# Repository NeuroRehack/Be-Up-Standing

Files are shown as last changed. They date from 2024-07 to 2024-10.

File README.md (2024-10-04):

## [🏠 HOME](./README.md) | [🔧 Firmware](Firmware/README.md) | [💻 Software](Software/README.md) | [📊 Analysis](Analysis/README.md)
# Desk Positioning System 

This project aims to monitor the usage of a standing desk by measuring its height and detecting whether someone is present. The Desk Positioning System utilizes an Omega2 Pro SBC (Single-Board Computer) to read data from a human presence sensor and a distance sensor, storing this data localy. The data is periodically uploaded to Google Drive for easy remote access and analysis.

<p align="center">
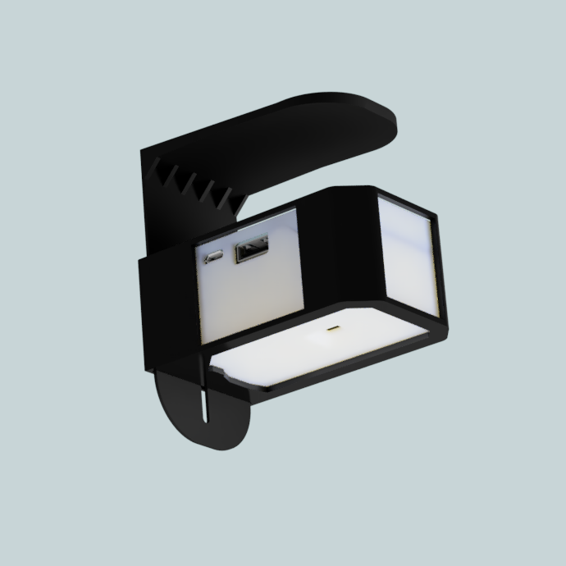
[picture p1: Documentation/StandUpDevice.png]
  
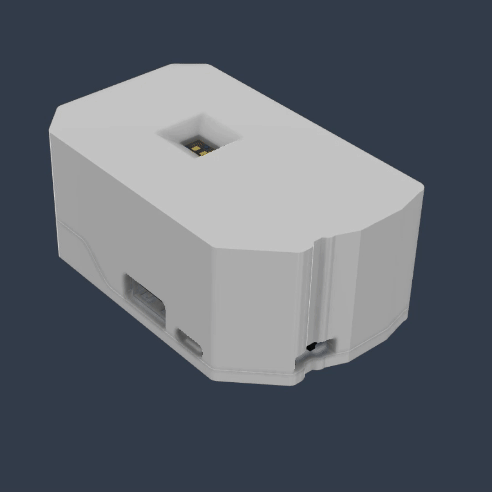
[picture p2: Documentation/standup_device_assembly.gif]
  
</p>

## Features
- **Desk Height Monitoring:** A laser distance sensor measures the distance between the desk and the floor, enabling the system to determine whether the desk is in a sitting or standing position.
- **Human Presence Detection:** An mmWave human presence detector identifies if a person is present and whether they are standing or sitting in front of the desk.
- **Data Logging:** Data from the sensors is processed and recorded by the Omega2 Pro, and timestamped using a real-time clock (RTC) module. The data is saved locally and periodically uploaded to Google Drive.
- **Power Management:** Powered by a rechargeable LiPo battery, the system remains operational during power outages.
- **Wi-Fi Connectivity:** The device uploads data to Google Drive when an internet connection is available. In case of network failure, data is stored locally for later upload.
- **Web Interface:** Each device hosts a unique web interface accessible via a specific URL, allowing users to:
  - Configure device settings (e.g., sampling frequency)
  - Start/stop data recording
  - Visualize recorded data in real-time
  - Manage Wi-Fi settings and monitor battery status
- **LED Indicator:** Provides visual feedback on operational status, such as internet connectivity and recording activity.

<p align="center">
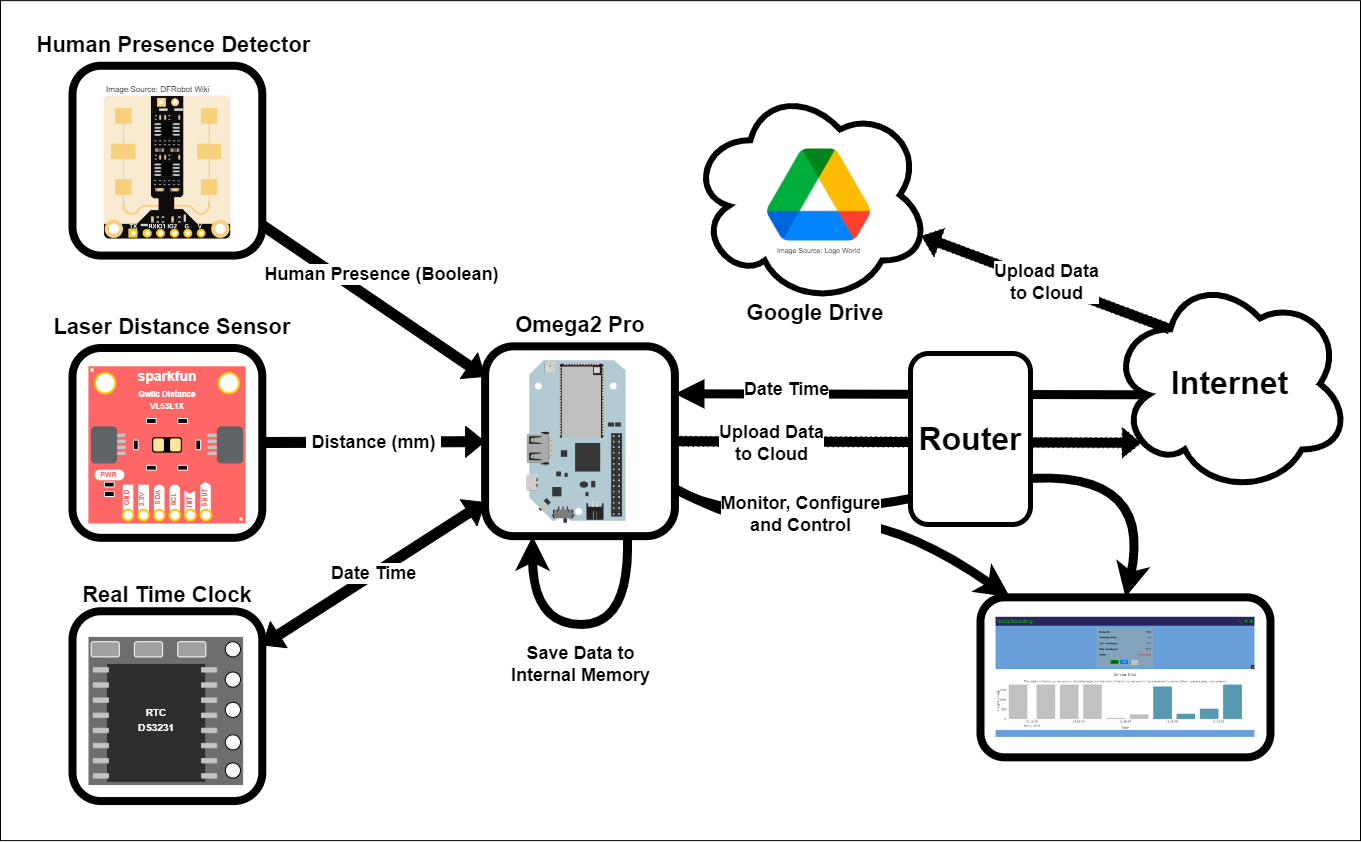
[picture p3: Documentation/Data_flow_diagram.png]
  
</p>

## Repo Overview
- **Firmware:** Contains the code running on the Omega2 Pro, responsible for data collection, processing, and cloud synchronization.
- **Software:** Includes scripts for downloading data from Google Drive
- **Analysis:** Provides instructions for analyzing the collected data to understand desk usage patterns.

## Getting Started
### Assembly and Setup

Follow the instructions in the [Firmware README](Firmware/README.md) to assemble the hardware and install the necessary firmware.

## Software

The scripts in software can be used to navigate, download and delete data from the google drive. For more information see the [Software README](Software/README.md).
## Data Analysis

The data collected by the Desk Positioning System can be analyzed to understand desk usage patterns. Detailed instructions for analyzing the data are available in the [Analysis README](Analysis/README.md).

## Desk Positioning System (DPS)

The Desk Positioning System (DPS) was developed to measure sit-stand desk usage in real-world settings. 
It has been created in collaboration with researchers from the School of Human Movement and Nutrition Sciences 
and the Neuroengineering, Rehabilitation, and Medical Robotics Group at the University of Queensland.

The system monitors desk height, detects human presence, and logs data for analysis. The device is managed through 
a web interface and can upload data to Google Drive.

---

## Getting Started

### Switching the Device On

The DPS device features two ports and one switch:

<p align="center">
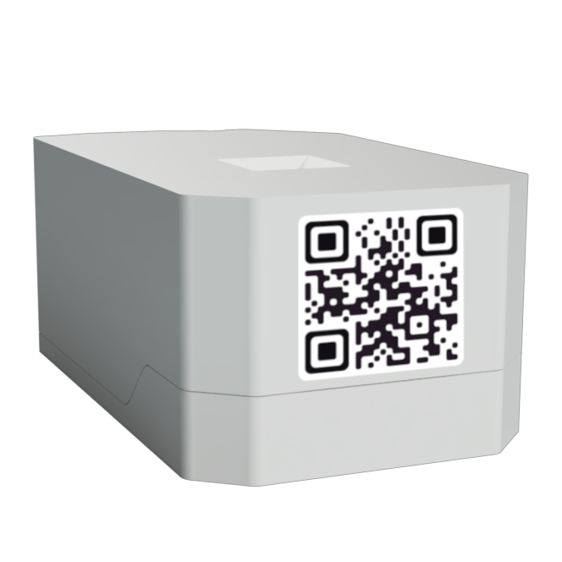
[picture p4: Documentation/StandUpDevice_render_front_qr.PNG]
  
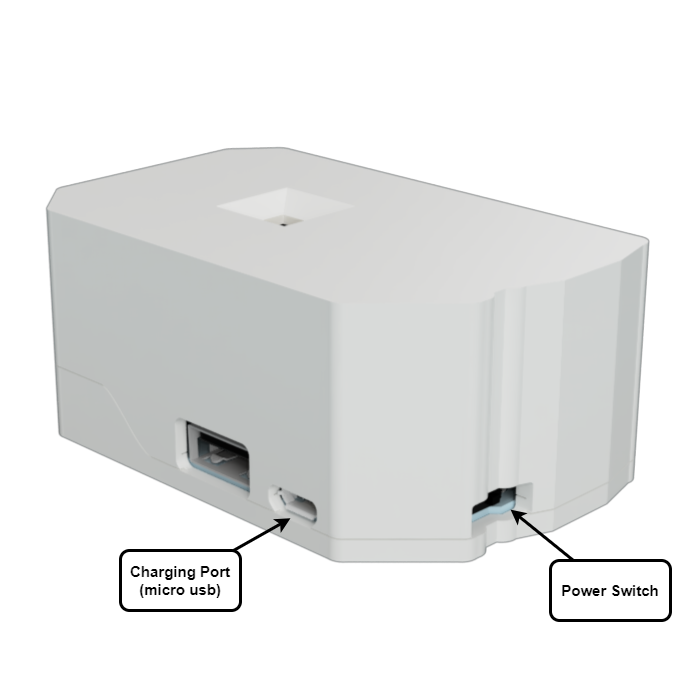
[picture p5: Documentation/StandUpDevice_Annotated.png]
  
</p>

- **USB Port**: Not currently in use.
- **Micro-USB Port**: Used for charging or providing power to the device.
- **Power Switch**: Used to turn the device on and off.

To start the device, switch it on using the power switch (connect it to a power source if necessary). 
The device should automatically start recording data.

### Accessing the Dashboard

To access the device’s dashboard, scan the provided QR code or enter the URL `dps-xxxx.local:5000` in your browser, replacing `xxxx` with the device's unique identifier. Ensure that the device and your computer are on the same network.

The home page asks the user to choose between two profiles, the guest or admin profile (default password : dps12345678). Both profiles allow the user to see the real time data and some of the devices’ parameters, and set the status LED intensity.

<p align="center">
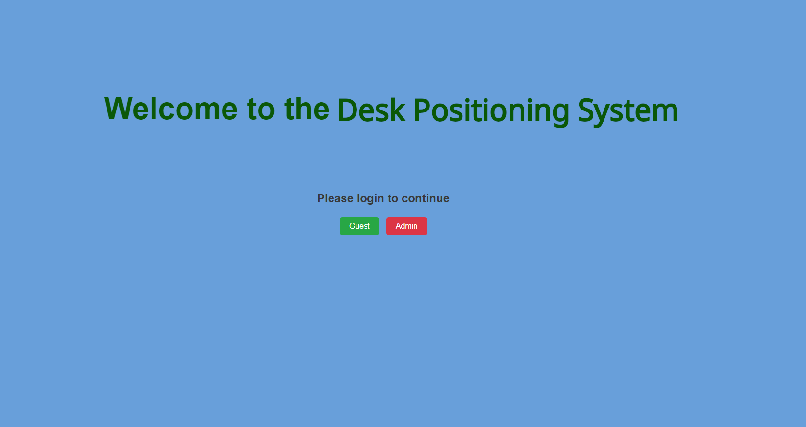
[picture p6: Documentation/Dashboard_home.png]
  
</p>

## Device Operation

Once logged in to the Admin Dashboard, you can monitor the device's parameters, start/stop recordings, and adjust settings.
<p align="center">
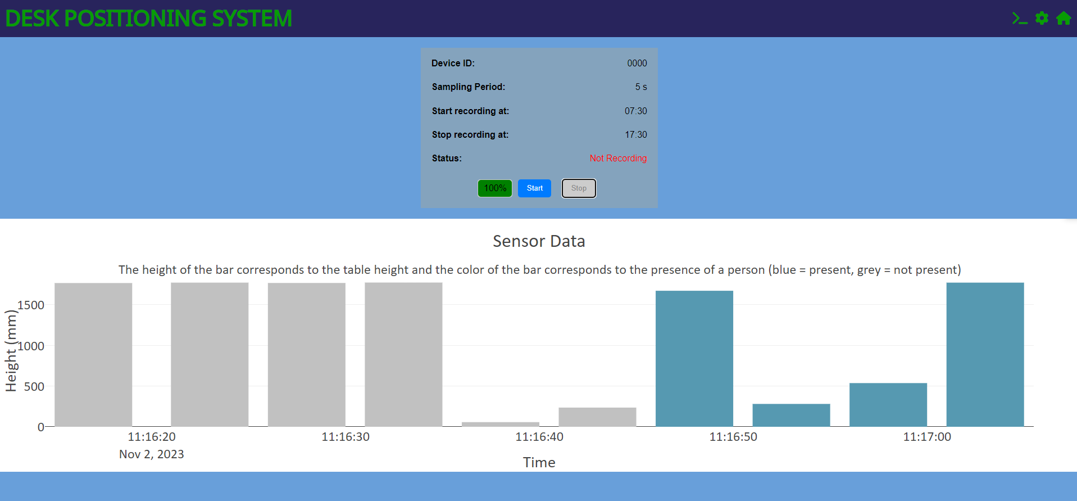
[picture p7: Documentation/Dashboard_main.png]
  
</p>

### Configuration

The settings window allows you to customize the following parameters:

- **ID**: Define a name for a recording session (e.g., `test_001`).
- **Start/Stop Recording**: Specify the time window for active recording.
- **Status LED Intensity**: Adjust the brightness of the status LED.

Advanced settings include:

- **Sampling Period**: Period between data sampling (seconds).
- **Write Period**: Period between writing data to a file.
- **New File Period**: Period after which a new file is created.
- **Upload Period**: Period between attempts of uploading completed files.

<p align="center">
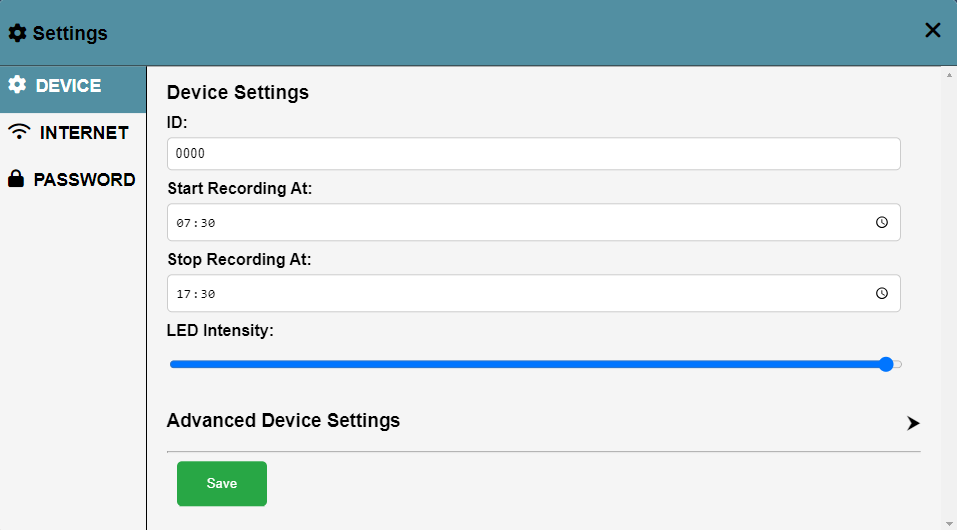
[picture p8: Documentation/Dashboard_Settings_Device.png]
  
</p>

### Recording

Recording starts automatically when the device is switched on, unless it was previously turned off in a non-recording state.

- **Stop Recording**: Press the “Stop Recording” button. The main LED will pulse red.
- **Start Recording**: Press the “Start Recording” button. The LED will pulse green (and blue if connected to internet). If the current time is outside the recording
window set in the configuration file, the colour of the LED will change to purple and pulsate more
slowly.

<p align="center">
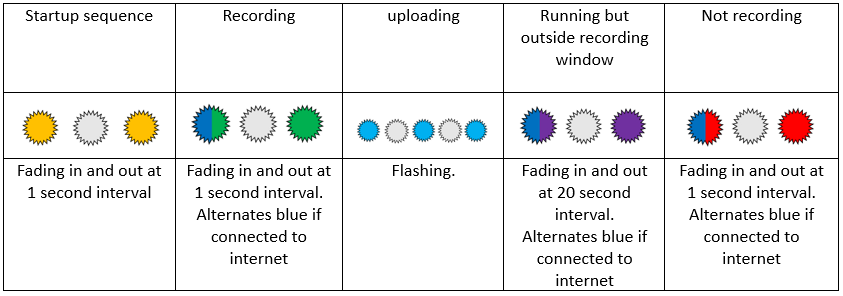
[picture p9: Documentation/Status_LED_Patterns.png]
  
</p>

### Device Placement

Proper placement of the Desk Positioning System (DPS) is crucial for accurate detection and measurement. Below are guidelines for placing the device in different environments:

#### Accurate Detection
- **Single Person Office:** The DPS will correctly detect the presence of the correct person when placed facing the user directly. This setup ensures that the sensor accurately detects both sitting and standing positions.

#### Situations with Inaccurate Measurement
- **Distance Measurement Issues:** When the device is placed at an angle where it cannot properly detect the distance between the table and the surface below, the DPS might still differentiate between sitting and standing, but the measurements will be less accurate.
- **Shared Office:** In a shared office environment, the DPS may not always detect the presence of the correct person if other individuals are within the detection range. It's important to position the device carefully to minimize interference.
- **Open Space Office:** Similar to a shared office, the DPS may not always detect the correct person in an open space office. Ensure the device's front is facing the intended user and minimize the chance of capturing passersby.

#### Incorrect Detection
- **Improper Placement:** If the DPS is placed facing away from the user or in a position where the sensor cannot accurately measure the distance to the surface, it will fail to correctly detect the user’s presence or their sitting/standing state.

#### Placement Tips
- **Orientation:** The device should be placed and oriented such that the front is facing the user, minimizing the chances of capturing passersby.
- **Placement**: Ensure the device is positioned at an angle where the distance sensor can accurately measure the height of the desk. Avoid placing the device in a corner or behind objects that may obstruct the sensors.

<p align="center">
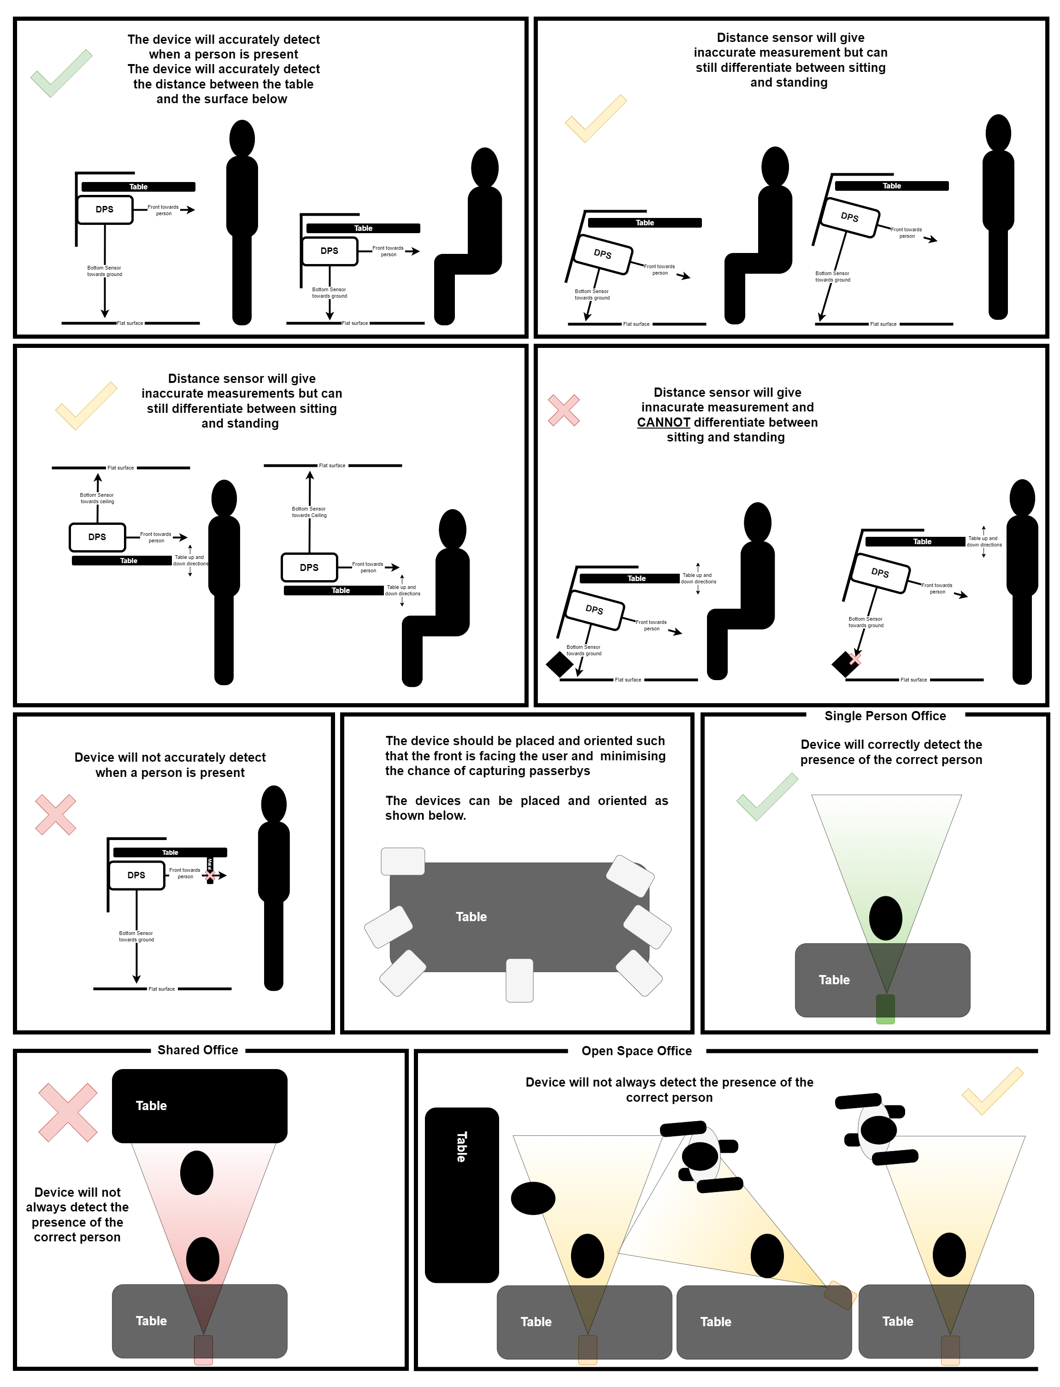
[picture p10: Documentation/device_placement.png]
  
</p>

## Data Handling

### Downloading the Data

Use the `drive_cloner_ui.exe` program to download data from Google Drive (see [Software README](Software/README.md) for more information). The program will sync and download the data, 
then clear the drive. It is recommended to run this program on a single computer to avoid data loss.

### Downloading Data Directly from the Device

If the data has not been uploaded to Google Drive, you can download it directly from the device using [WinSCP](https://winscp.net/eng/index.php). 
Connect your computer to the device’s Wi-Fi or the same network, then use the following credentials:

- **Hostname**: `standup-xxxx.local`
- **Username**: `root`
- **Password**: `beupstanding` (default)

<p align="center">
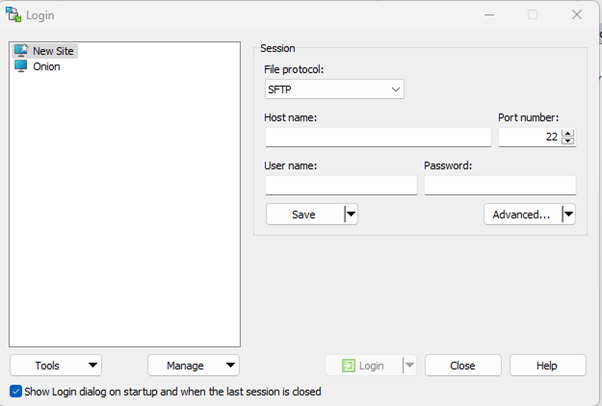
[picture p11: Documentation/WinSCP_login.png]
  
</p>

Once the session is established the folder structure of the device is shown on the right-hand side,
and the folder structure of your computer is shown on the left-hand side. On the device navigate to
the Firmware folder and on the computer navigate to where you would like to download the data to.
On the computer create a folder which name is the ID of the device. You can then simply select the
“data” folder on the device side and drag it to the created folder on the computer side to copy it.

<p align="center">
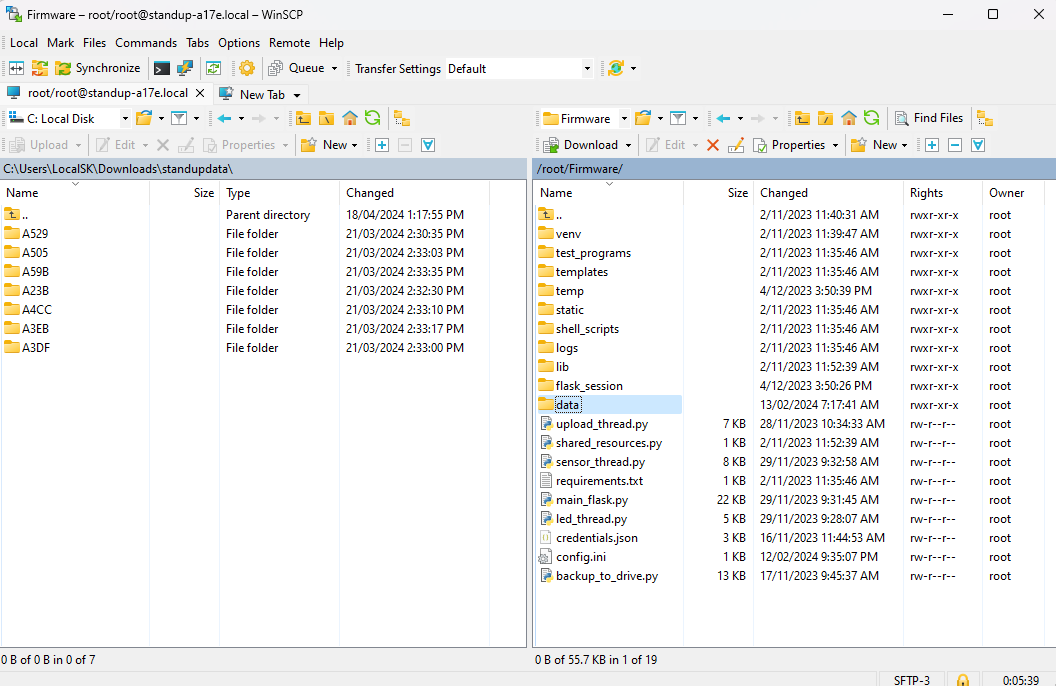
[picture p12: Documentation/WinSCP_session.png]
  
</p>

---
## License

This project is licensed under the GNU General Public License. You may redistribute and/or modify it under the terms of the [GPL version 3](https://www.gnu.org/licenses/gpl-3.0.html) (or any later version) as published by the Free Software Foundation.

For more details, see the [LICENSE](LICENSE) file.

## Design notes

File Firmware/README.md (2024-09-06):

<!-- add a link to go back to main readme file -->
## [🏠 HOME](../README.md) | [🔧 Firmware](./README.md) | [💻 Software](../Software/README.md) | [📊 Analysis](../Analysis/README.md)

## Required material
- [Omega2 Pro](https://onion.io/store/omega2-pro/)
- [DFRobot_mmWave module](https://www.dfrobot.com/product-2282.html)
- [PiicoDev_VL53L1X module](https://www.sparkfun.com/products/14722)
- [SDL_DS3231 module](https://www.jaycar.com.au/rtc-clock-module-for-raspberry-pi/p/XC9044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)
- [LiPo battery 3.7V 1100mAh](https://core-electronics.com.au/polymer-lithium-ion-battery-1000mah-38458.html)
- 5 x Male to Female Jumper wires
- 2 x Male to QWIIC Jumper wires (4-pin)
- USB A to micro USB cable
- M3 Nylon 16mm screws and nuts

## Required equipment
- 3D printer
- Soldering iron
- Hot glue gun (optional)
- Computer
- Internet connection

## Required skills and experience
- 3d printing
- Soldering
- SSH and serial terminal
- Basic knowledge of linux navigation and commands

## Hardware setup 
### Wiring (~15 min)
Once you have all the necessary components, you can start assembling the hardware. The wiring schematic below shows how to connect the various components to the Omega2 Pro. 
This step may require you to solder pins onto some of the sensors. Wiring should take around 10-15 minutes.

<p align="center">
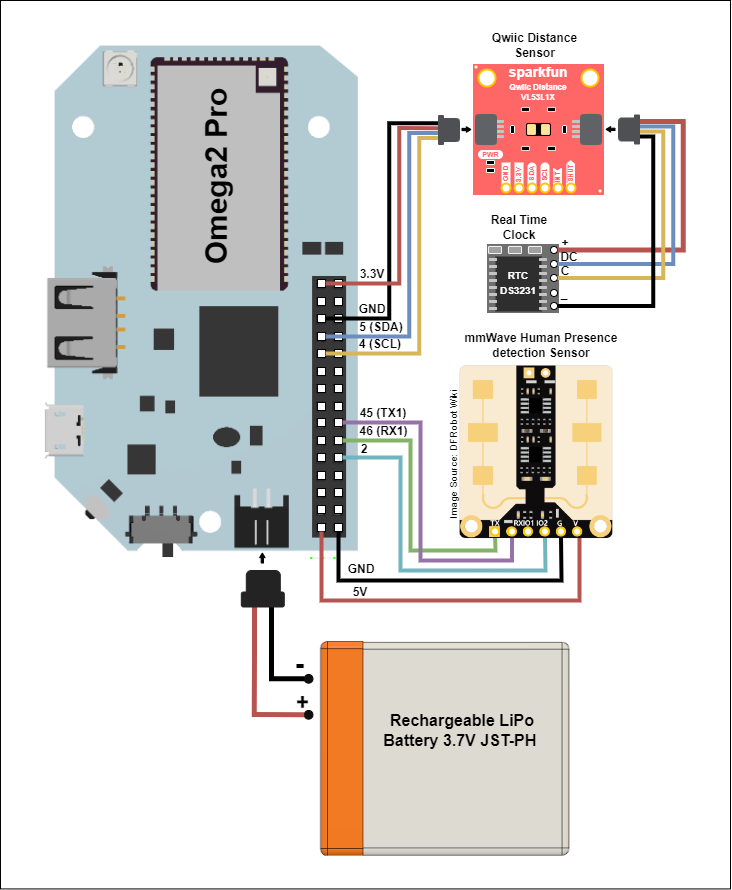
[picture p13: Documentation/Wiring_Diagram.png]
  
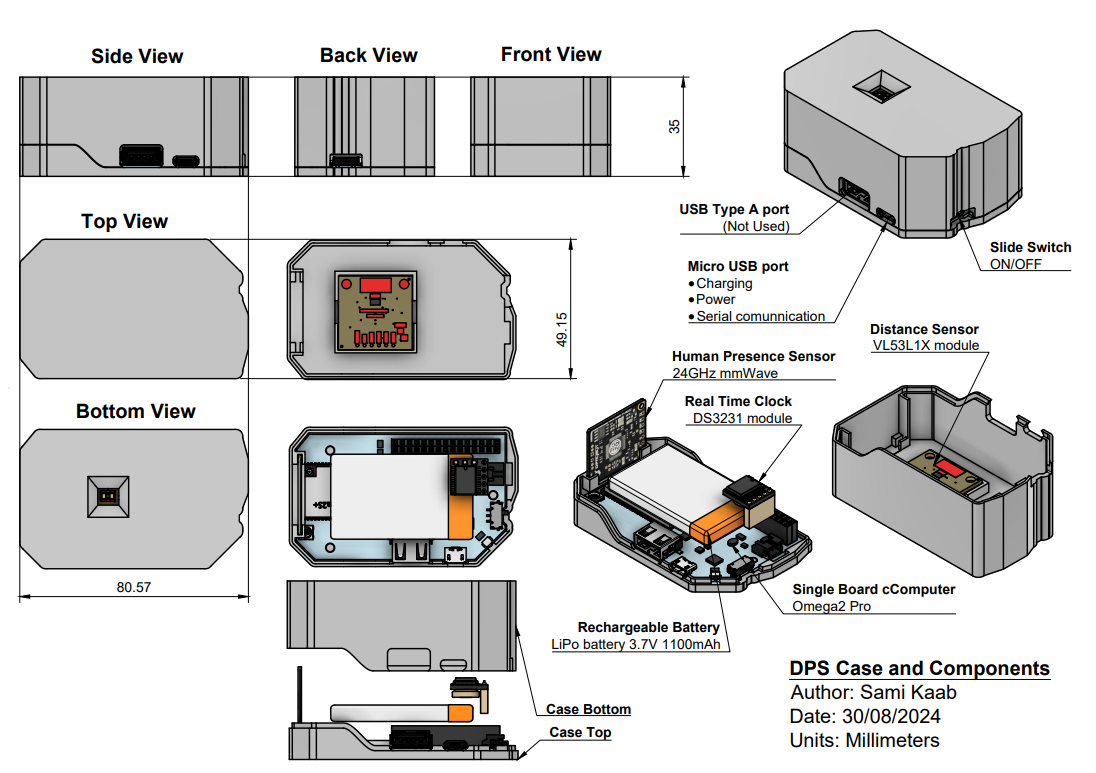
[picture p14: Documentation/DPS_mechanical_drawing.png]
  
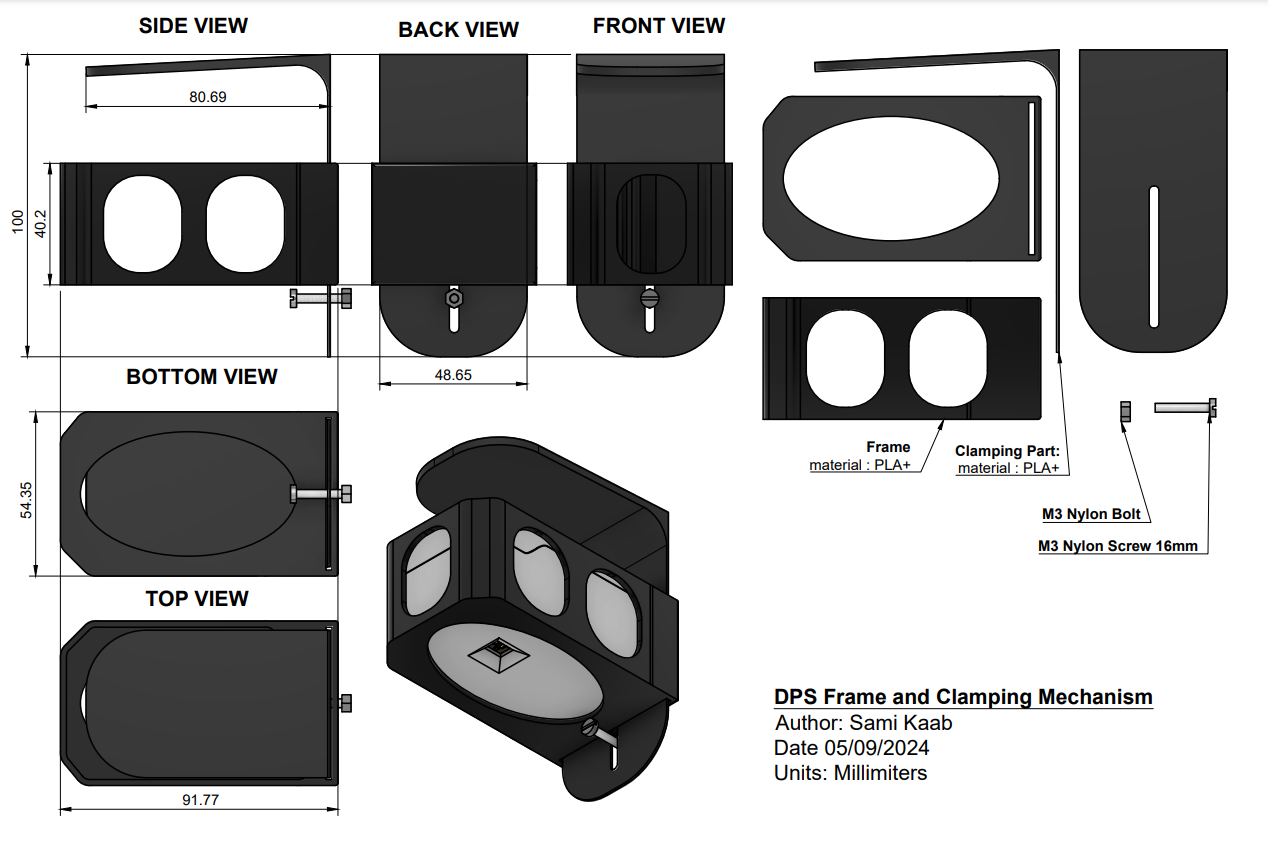
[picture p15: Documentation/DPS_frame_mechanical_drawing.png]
  
</p>

### 3D printing the case (~3 hours)

You will need to 3d print a case to house the components and the frame to attach the device to the desk. The STL files can be found in the [CAD folder](../Documentation/CAD/). Make sure to print one of each of the following files:
- [Case Bottom](../Documentation/CAD/case_bottom.obj)
- [Case Top](../Documentation/CAD/case_top.obj)
- [Frame](../Documentation/CAD/frame.obj)
- [Clamping Part](../Documentation/CAD/clamping_part.obj)

On a printer with 0.2mm layer height, supports (64° overhang threshold), 10% infill, 250mm/s, it should take around 3 hours to print all the parts.

## Setting up a google drive API (~10 min)
The data recorded is uploaded to a google drive using the google drive api. For the program to use the api it is necessary to generate a credentials file.
You can find instructions on how to set up a google drive api [here](https://developers.google.com/drive/api/quickstart/python).  
Since we are using a headless device it is not possible for us to generate tokens which are necessary when using a normal google account and require a webbrowser based authentification which we cannot perform. For this reason make sure to link a google service account to the project.

You will have to copy the credentials to the Firmware folder on the Omega2 Pro and rename it "credentials.json". This will be done in the next section. 

You will also need it for accessing the google drive using the scripts in the Software folder (see the [Software README](../Software/README.md)).

## Setting up the Omega2 Pro (~30 min)
The Omega2 Pro is a headless device, meaning that it cannot be accessed using a graphical user interface. In order to set it up you need to plug it to a computer using a micro USB cable and connect to it using a serial terminal (e.g. Putty). The device requires internet access in order to install the necessary packages. This section should take around 30 minutes to complete depending on the internet connection.

- Once you have connected to the device using a serial terminal, you can set up the wifi using the following command:
  ```sh
  wifisetup add -ssid <ssid> -encr psk2 -password <password>
  ```
  Replace ssid and password with the name and password of your wifi network.

- Copy the credentials file to the Firmware folder on the Omega2 Pro.
  You can do this using scp:
  ```sh
  scp /path/to/credentials.json root@Omega-XXXX.local:/root/Firmware/credentials.json
  ```
  where /path/to/credentials.json is the path to the credentials file on your computer and `XXXX` is the last four digits of the Omega2 Pro ID.
- You should now have internet access, which you can verify by pinging a website:

  ```sh
  ping duckduckgo.com
  ```

  - We first need to install git and ca-bundle in order to be able to clone the repository:
  ```sh
  opkg update && opkg install git git-http ca-bundle
  ```
- We can now install the necessary Omega2 and python packages.

  - Download the source code from the latest release of the repository to your computer. Extract the files and copy the Firmware folder to the root of the Omega2 Pro. You can do this using scp:
  ```sh
  scp -r /path/to/Firmware root@Omega-XXXX.local:/root/
  ``` 
  where /path/to/Firmware is the path to the Firmware folder on your computer and `XXXX` is the last four digits of the Omega2 Pro ID.
  
  **NOTE**: You will need to have the Omega2 Pro connected to the same network as your computer.

  - **Alternatively**, you can clone the repository directly on the Omega2 Pro using git:

  ```sh
  cd /root && git init && git config core.sparseCheckout true && echo Firmware/ >> .git/info/sparse-checkout 
  ```
  ```sh
  git remote add origin https://github.com/NeuroRehack/Desk-Positioning-System.git && git pull origin master
  ```

- then navigate to the Firmware folder and run the setup script which will install the necessary packages and set up the Omega2 to run the program on startup.
  ```sh
  cd /root/Firmware && source /root/Firmware/shell_scripts/set_up.sh
  ```
  depending on the internet connection the setup might take a while. Once it is done you will need to reboot the device using ```reboot```.

- It is a good idea now to check that the sensors have been wired and are working correctly. You can do this by running the test script:
  ```sh
   source /root/Firmware/shell_scripts/run_test.sh 
  ```

- Next run the omega_rename script:
  ```sh
  source ./shell_scripts/omega_rename.sh
  ```
  This script will amongst other things change the default wifi name and password of the omega as well as the device's password.

The device should now be ready for use. Just restart it using ```reboot``` and it should start running the program on startup.

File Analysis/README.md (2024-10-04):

## [🏠 HOME](../README.md) | [🔧 Firmware](../Firmware/README.md) | [💻 Software](../Software/README.md) | [📊 Analysis](./README.md)
This fodler contains a collection of Python scripts designed to process and analyze data collected from the standup device. The data analysis focuses on determining sitting and standing periods, transitions between these states, and human presence during work hours. The scripts generate detailed analysis results and visualizations, including time series plots, transitions, bouts, workday schedules, and time spent at or away from the desk.

## Scripts Overview

### 1. `convert.py`
The `convert.py` script is designed to batch process raw CSV data files by converting them into a more efficient Parquet format, which is better suited for subsequent analysis. This script is particularly useful when dealing with large datasets collected over multiple sessions.

#### Key Features:
- **Batch Processing**: Recursively identifies and processes all CSV files within a specified directory.
- **Session Management**: Groups files based on session identifiers derived from the filenames, ensuring that data from the same session is processed together.
- **Data Processing**: Merges the data from multiple files, converts datetime fields, and adjusts the data format for analysis.
- **Parallel Processing**: Utilizes multithreading to speed up the processing of multiple sessions simultaneously.
- **Output Formats**: Saves the processed data in both Parquet and CSV formats for flexibility in usage.

#### Usage:
1. **Input Directory Selection**: The script prompts the user to select a directory containing the raw CSV files.
2. **Output Directory Selection**: The user is prompted to select a directory where the processed files will be saved.
3. **Execution**: The script processes the files in batches, converting and saving them in the desired formats. Progress is displayed in real-time.

This script is essential for preparing raw data for analysis by ensuring it is organized, processed, and stored in a format that facilitates faster and more efficient analysis.

### 2. `main.py`

The `main.py` script serves as the primary entry point for analyzing standup data collected over a specified period. It automates the process of reading, processing, and generating visual analysis from data files, providing insights into user activity such as sitting, standing, and presence transitions. Read more about the data analysis workflow [here](#data-analysis-workflow).

#### Key Features:
- **Data Loading**: Reads standup data from Parquet files located in a user-specified directory.
- **Data Processing**: Cleans the data, removes outliers, and computes key metrics such as sitting and standing percentages, transitions between these states, and bouts of activity.
- **Analysis and Metrics**: Computes various metrics:
  -  Total data duration
  - Percentage of time spent sitting and standing each day
  - Sit-stand transitions
  - Presence transitions
  - Bouts of sitting and standing
  - Total time spent at the desk each day
- **Visualization**: Generates various plots to visualize the analyzed data, including time series plots, transition plots, workday summaries, and more.
- **Output**: Saves the generated plots as interactive HTML files in a user-specified output directory.

#### Usage:
1. **Directory Selection**: The script prompts the user to select directories for both input (where the data files are stored) and output (where results will be saved).
2. **Execution**: Once the directories are specified, the script processes all relevant data files, performs the analysis, and generates visualizations. Progress is displayed throughout the process.

Make sure to have run the `convert.py` script on the raw data files before using `main.py` for analysis.

### 3. `plotting.py`
The `plotting.py` script provides a collection of functions for generating detailed visualizations of standup data. It is used as a library of plotting functions by the main.py script to create various plots, including time series plots, transition plots, workday summaries, and more.

### 4. `analysis.py`
The `analysis.py` script contains functions that perform the core data analysis tasks on standup data. It includes functions for cleaning the data, computing metrics, identifying transitions, and calculating bouts of sitting and standing. These functions are used by the `main.py` script.

### 5. plot_standup_data.py
The `plot_standup_data.py` script is a standalone script that generates time series plots of standup data for a specified date range. It allows users to visualize the distance measurements and human presence data over time.
 
## Setup and Dependencies
The data analysis scripts are written in Python. it is recommended to use a virtual environment to manage the dependencies. To create a virtual environment, run the following command:
```bash
python -m venv venv
```
to install the required dependencies, run the following command:
```bash
pip install -r requirements.txt
```

## Data Analysis Workflow 
<p align="center">
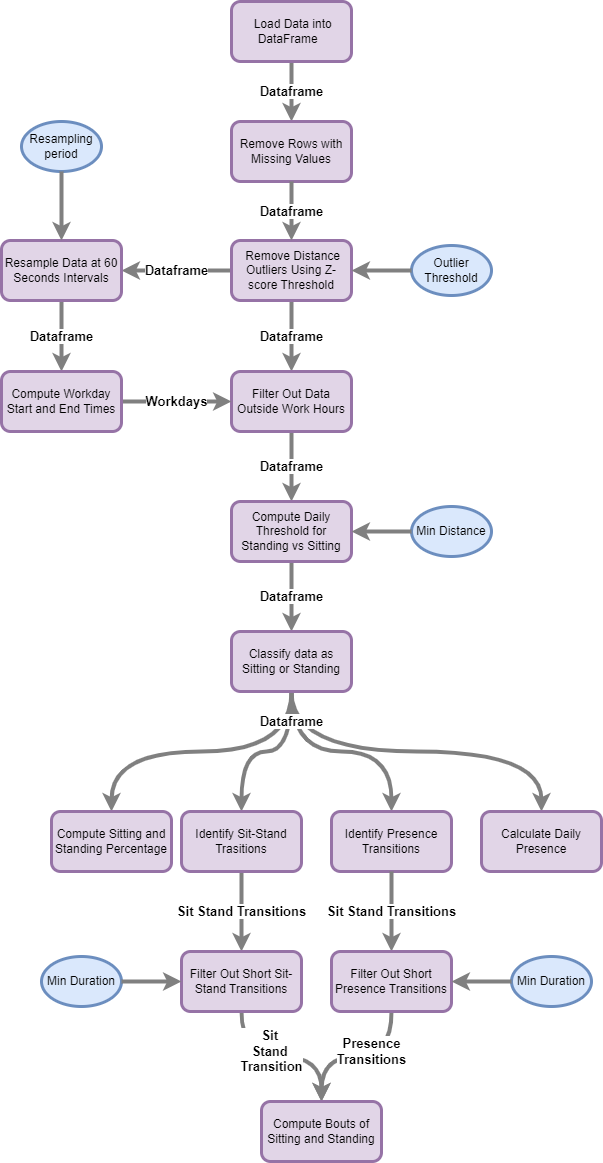
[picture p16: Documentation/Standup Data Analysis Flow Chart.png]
        
</p>

The data is initially loaded into a pandas DataFrame, where rows containing missing values are removed. To further clean the data, rows with outlier distance values are filtered out using a specified z-score threshold. This z-score represents the number of standard deviations a data point is from the mean. If a data point falls outside a predefined range (e.g., beyond ±4 standard deviations), it is classified as an outlier and removed. This step helps eliminate extreme values caused by brief manual handling of the device.

The data is then resampled at a defined interval (60 seconds in this case), which involves calculating rolling means for the 'Distance (mm)' column and determining the minimum value for the 'Human Present' column over each resampling period. This effectively returns `True` only if someone is present for more than a minute. Next, the start and end times of each workday are identified based on when human presence is first and last detected. Data points outside these computed work hours are filtered out, ensuring the analysis accurately captures the standing-to-sitting ratio during work hours, excluding any presence detected outside these times. The assumption is that any presence lasting longer than 60 seconds corresponds to the desk user, while shorter presences are disregarded.

The subsequent analysis is performed on the original, non-resampled data. A daily threshold for determining standing versus sitting is calculated based on distance measurements. This involves grouping the data by date and calculating the mean distance for each day, provided that the variability in distance measurements is sufficient. If the difference between the maximum and minimum distance values is smaller than a predefined threshold, the analysis flags the day as invalid by returning -1. These thresholds are then applied to the original data to classify whether the user is standing or sitting at each timestamp.

A new column, 'Standing,' is added to the DataFrame, where a value of `True` indicates the user is standing (distance greater than the threshold), and `False` indicates sitting. Transitions between sitting and standing are tracked by creating two new columns, 'TransitionToUP' and 'TransitionToDown.' The 'TransitionToUP' column flags transitions from sitting to standing, while 'TransitionToDown' flags the opposite. Additionally, transitions between presence and absence at the desk are captured in two more columns: 'PresentToAbsent' and 'AbsentToPresent.'

Several metrics are calculated to analyze the user's behavior. The total data duration is computed as the time span between the earliest and latest timestamps. The percentage of time spent sitting and standing each day, while the user is present, is calculated by dividing the time spent in each position by the total presence time. Sit-stand transitions are filtered to exclude transitions shorter than a specified minimum duration (120 seconds), ensuring that only significant changes are considered. Presence transitions, which track when the user arrives at or leaves the desk, are also filtered to retain only transitions lasting at least 60 seconds.

Finally, bouts of sitting and standing are calculated, considering both presence and height transitions. A bout is defined as a continuous period where the user is either sitting or standing while present at the desk. These bouts provide insights into uninterrupted sitting or standing periods. The total time spent at the desk each day is also calculated by summing all periods marked as 'Human Present,' offering a clear picture of the user's desk usage patterns.

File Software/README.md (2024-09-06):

## [🏠 HOME](../README.md) | [🔧 Firmware](../Firmware/README.md) | [💻 Software](./README.md) | [📊 Analysis](../Analysis/README.md)

This project provides a set of Python scripts and user interfaces to interact with Google Drive, enabling users to clone, manage, and manipulate files and folders. The project consists of three primary components: `drive_cloner.py`, `drive_cloner_ui.py`, and `drive_ui.py`. These components work together to automate the process of downloading files from Google Drive, verifying their integrity, and removing them from the cloud once successfully downloaded.

## Scripts Overview

### 1. `drive_cloner.py`

This script interacts with Google Drive via the Google Drive API to manage files and folders. Given a folder ID, the script lists all files and folders within the specified folder, and based on their MIME types, downloads them to a local directory. If a folder is empty and is not the root, it deletes the folder from Google Drive. After downloading, it checks the integrity of the download using an MD5 hash and deletes the source file from Google Drive if the integrity check passes. The script also provides utility functions for listing and printing the folder structure in Google Drive, as well as deleting all files.

### 2. `drive_cloner_ui.py`
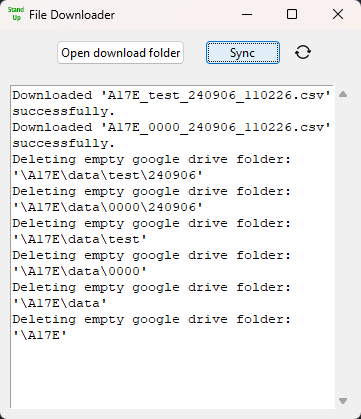
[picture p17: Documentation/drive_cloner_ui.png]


This script provides a Tkinter-based GUI application named "File Downloader" for downloading files from Google Drive. It allows users to specify a local directory to download files to, and it keeps the local directory synced with Google Drive by downloading files and removing them from Google Drive once successfully downloaded. The user can monitor progress and messages through a scrollable log window within the application interface.

### 3. `drive_ui.py`
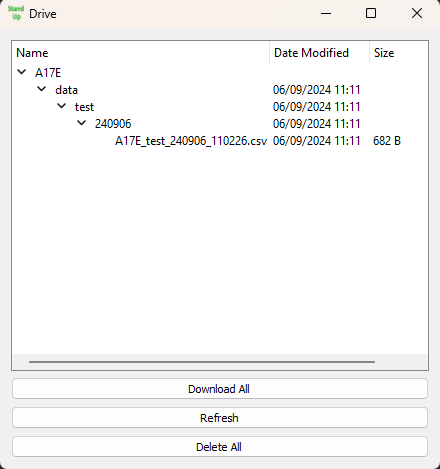
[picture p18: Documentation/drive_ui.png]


 This script utilizes PySide2 to create a graphical user interface (GUI) application for interacting with Google Drive. The application enables users to browse, download, and delete files and folders in their Google Drive. The application is particularly equipped to handle these tasks while displaying progress and alerting users through a UI.

## Installation

### Prerequisites
- Python 3.7 or higher
- Required Python packages: Install using `pip install -r requirements.txt` or manually install the following packages:
  - `google-api-python-client`
  - `google-auth-httplib2`
  - `google-auth-oauthlib`
  - `requests`
  - `PySide2` (for `drive_ui.py`)
  - `tkinter` (for `drive_cloner_ui.py`)

### Setup
1. **Google API Credentials**:
   - Obtain a service account JSON file (`credentials.json`) from the Google Cloud Console (see [Firmware README](../Firmware/README.md) for more details).
   - Ensure the service account has the necessary permissions to access and modify your Google Drive files.
   
2. **Configuration**:
   - Ensure that the `drive_settings.ini` file is correctly set up with your desired download path if using `drive_cloner.py`.

## Usage

### Drive Cloner (Command Line)
- Simply run `drive_cloner.py` to start downloading files from Google Drive to the configured local directory. The script will automatically verify file integrity and delete files from Google Drive once successfully downloaded.

### Drive Cloner UI
- Launch the GUI with `drive_cloner_ui.py`. Use the buttons provided to start syncing your Google Drive content. The GUI will display progress and logs to keep you informed.

### Drive UI
- Start `drive_ui.py` to use the advanced interface, which allows for more granular control over your Google Drive files. You can browse, download, and delete files directly from the application.

## Acknowledgements

- **Google API Python Client** for providing the necessary tools to interact with Google Drive.
- **PySide2** and **Tkinter** for making GUI development accessible and straightforward.

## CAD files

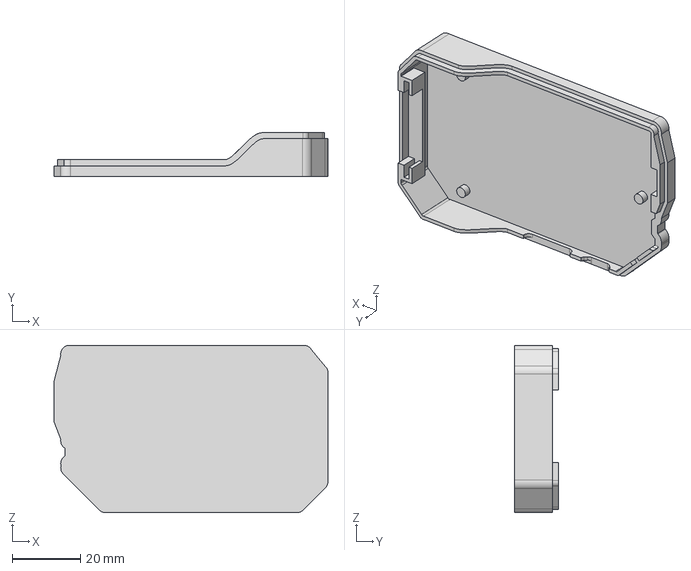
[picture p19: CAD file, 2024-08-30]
Documentation/CAD/case_top.step
80.6 x 12.9 x 49.2 mm

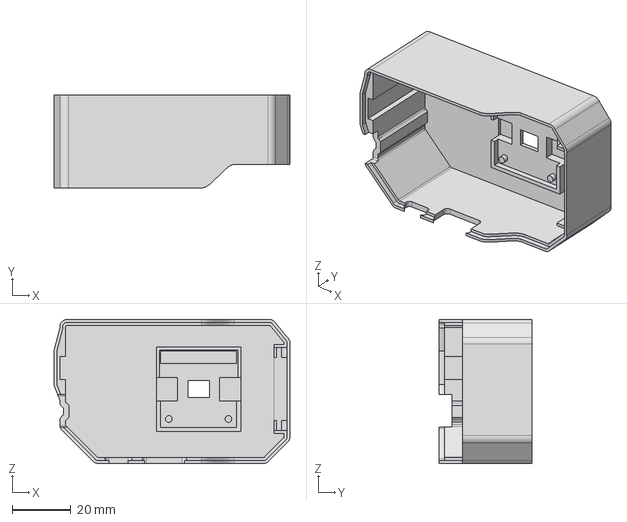
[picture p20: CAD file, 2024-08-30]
Documentation/CAD/case_bottom.step
80.6 x 31.7 x 49.2 mm

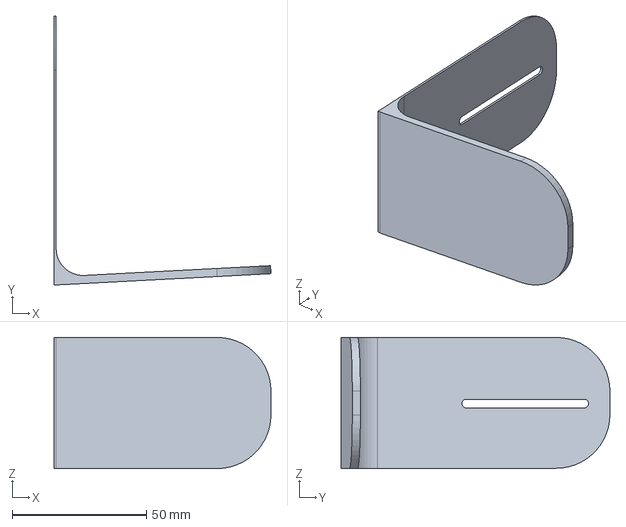
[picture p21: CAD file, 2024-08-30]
Documentation/CAD/clamping_part.step
80.7 x 100.0 x 48.8 mm

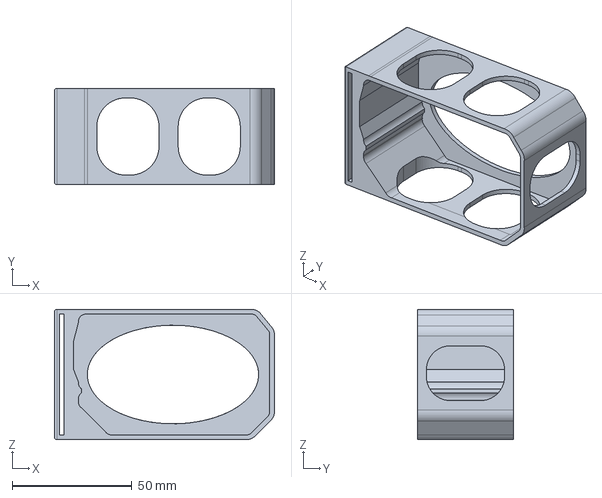
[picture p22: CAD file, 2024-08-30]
Documentation/CAD/frame.step
91.8 x 40.2 x 54.4 mm

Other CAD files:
Documentation/CAD/table_attachment.step
Documentation/CAD/case_Top.obj
Documentation/CAD/case_bottom.obj
Documentation/CAD/clamping_part.obj
Documentation/CAD/frame.obj

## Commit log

2024-03-28 Adds setup step to disable factory reset from button
2024-07-18 Adds data analysis flowchart and device assembly gif
2024-07-18 Adds table attachement step files
    [table_attachement2.step, table_attachment.step]
2024-07-18 Adds device image
2024-08-30 Rename and update CAD file and add Step Files
    [case_Top.obj, case_bottom.obj, case_bottom.step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]
2024-09-02 Update file paths in analysis and plotting scripts, remove sample data and output
2024-09-06 changes name of device in webapp and local url
2024-10-04 Update device URL and profile information in README.md
2024-10-04 Updates led status table
